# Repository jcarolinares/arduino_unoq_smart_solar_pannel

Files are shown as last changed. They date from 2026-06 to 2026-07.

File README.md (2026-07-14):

# 🌞 UNO Q Smart Solar Pannel

A small solar pannel system that orient solar pannels automatically to get as much energy as possible, protects them from overheat and extreme weather conditions, and autoclean them using the Arduino UNO Q advanced Edge AI Features.

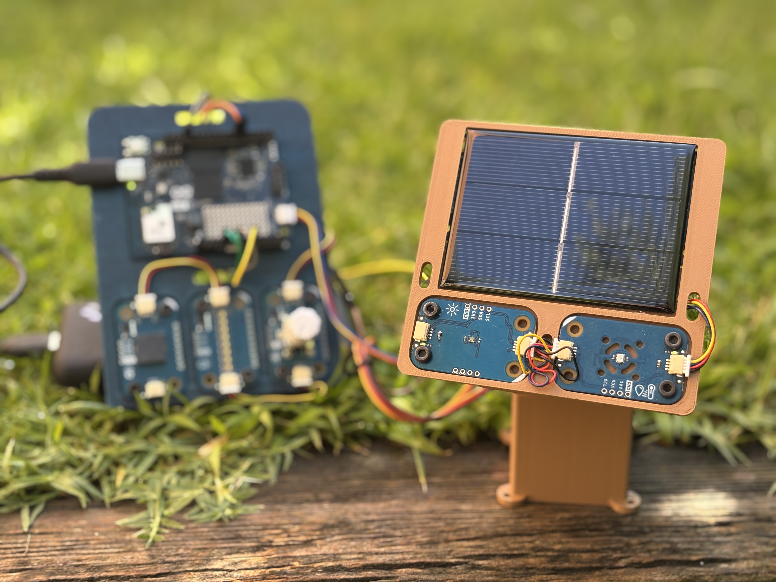
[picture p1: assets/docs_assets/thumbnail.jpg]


Youtube video below:

<a href="http://www.youtube.com/watch?feature=player_embedded&v=w9L78aqJsKc
  " target="_blank">Arduino UNO Q Solar Panel</a>

The UNO Q Smart Solar Panel system it is a little project intended to be used to learn about Edge AI applied to Green Energy Systems like Solar Panel systems. It is fully open sourced and you can 3D printed, mount and program it on your own!

[Youtube Video Link](https://youtu.be/w9L78aqJsKc)

## Features

* Fully accesible and Open Source, 3D print the pieces and use the cheap solar panel, servomotors and Modulinos to make it work.
* The system scan the sky and save the information into a database auto orienting the sonal panel to the best position to get more energy at any time.
* The Linux system take cares of Edge AI features, like general forecast, interactive local dashboard and much more, while the microcontroller gets information from the sensors and move the servomotors.
* If the weather forecast is snowy, or there is a sand's storm incoming, the Linux system informs the microcontroller to put the solan panel in emergency mode, keeping the solar panel as vertical as possible to protect it from the sand, snow, etc.
* If it is night or foggy, being too dark to get energy from the sand, the solar panel will read the low values of voltage and put it in home position (panel in horizontal) waiting for the right conditions to get energy again.
* The system is able to get not only read the values from the actual energy of the solar panel, but also get the infrared values of the sun thanks to the Modulino light. Which makes the system more efficient and able to detect where is position to get more energy from the sun.
* Thanks to the Modulino Thermo, system is able to know the temperature and humidity of the solar panel in real time. Protecting the solar panel when temperatures reachs danger limits for the panel like more than 60 celsius degrees.
* The solar panel is able to detect anomaly vibrations thanks to the Modulino IMU, stopping the whole system in case a serious problem is detected.
* The system is able to autoclean itself from dust, snow and sand, thanks to the Modulino Vibro, that makes, like Nasa's martian rovers do, to vibrate the whole solar panel to clean it.

### The real-time dashboard

The project shows on your network a small webpage dashboard with all the information in real time about what is happening.

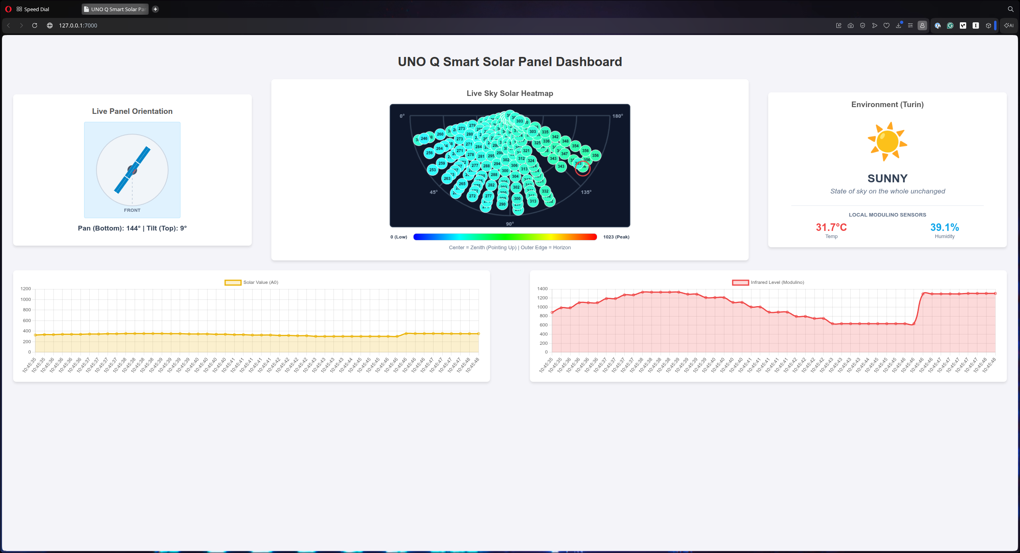
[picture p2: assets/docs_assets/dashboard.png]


* The Solar Panel orientation in real-time.
* The Live Sky HeatMap about the solar voltage readings from the solar panel to understand the best position for getting energy and the current position of the solar panel.
* The actual weather forecast of the place where the solar panel is installed and the real-time temperature and humidity of the solar panel itself.
* A real-time graph about the energy taking by the solar panel overtime.
* A real-time graph about the infrared light that the solar panel is getting overtime.

## Hardware Required

- 1x Arduino UNO Q
- 1x Small Solar Panel of 80 cm x 60 cm with a maximum voltage of 3 VDC.
- 2x Servomotors MG90 to move the solar panel.
- 1x Modulino Movement to detect sanomalies in the movement or even raining drops!
- 1x Modulino Light to read natural and infrared light
- 1x Modulino Vibro to autoclean the solar panel making it to vibrate.
- 1x Modulino Thermo to get the temperature and humidity of the solar panel

## Software Required

- Arduino App Lab
- Internet connection

## 3D Printed Parts

You can find the 3D parts to print and Freecad source file at the folder "3D Models" inside this repository.

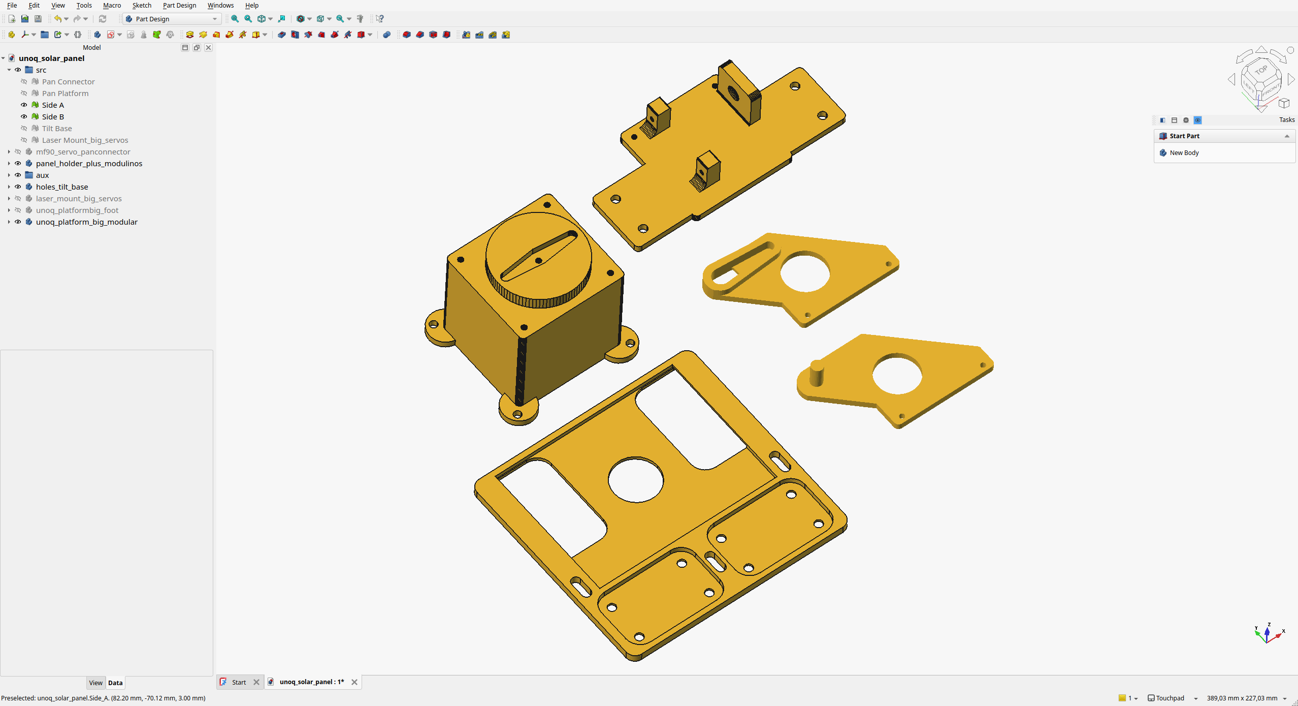
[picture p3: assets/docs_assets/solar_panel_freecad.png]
Freecad Solar Panel Parts


### 3D Printing

No special instructions are required to print your solar panel. Standard PLA is a good material to use but if you are going to put your solar panel long hours exposed to the sun can be melted easily, consider to print the parts in PETG if that is the case.
No supports are required. Use standard 15%/20% Infill and a nice 0.2 layer height.

### Assembly

Assembly is extremely easy, just follow the original instructions [here](https://www.hackster.io/TheSmallWonder/pan-tilt-assembly-for-mg90s-servos-da32c).

### Credits about the 3D parts

The design was created using as a base the project made by "The Small Wonder"

[Pan & Tilt Assembly for MG90S Servos](https://www.hackster.io/TheSmallWonder/pan-tilt-assembly-for-mg90s-servos-da32c6)

This design was used as base and some pieces were reused while another new parts were totally created from scrach, some of them were customized too. Use the Freecad file to make your own modifications if need, like adapting the solar panel holder piece for any other kind of solar panel!

## License

This project was created by Julián Caro Linares for Arduino INC under an Open Source Creative Common Share Alike license, CC-BY-SA

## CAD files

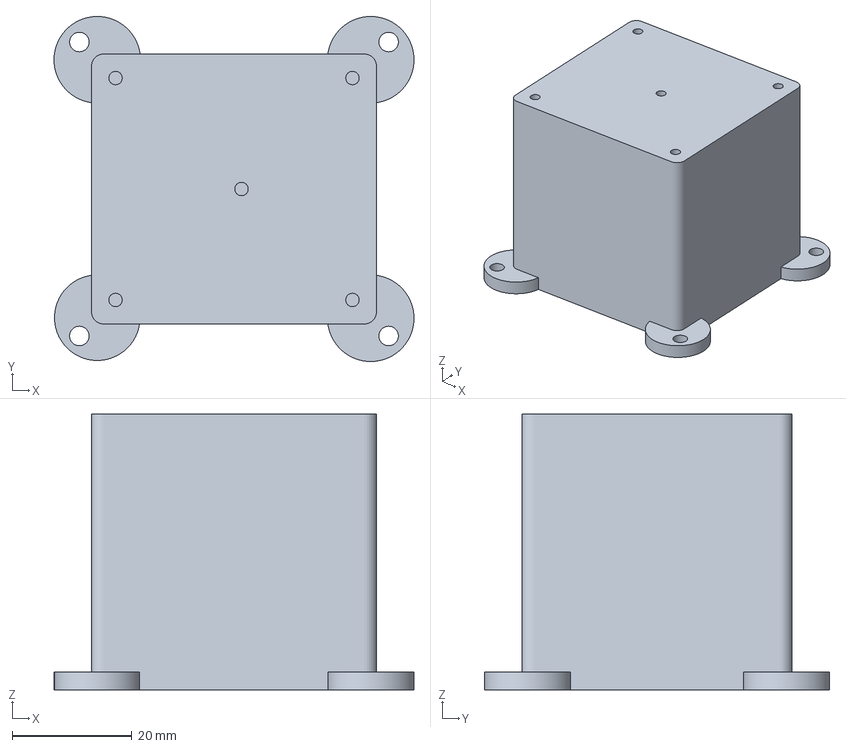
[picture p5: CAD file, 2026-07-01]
3D Models/v0_unoq_solar_panel-unoq_platform_big_modular.3mf
60.0 x 57.5 x 46.0 mm

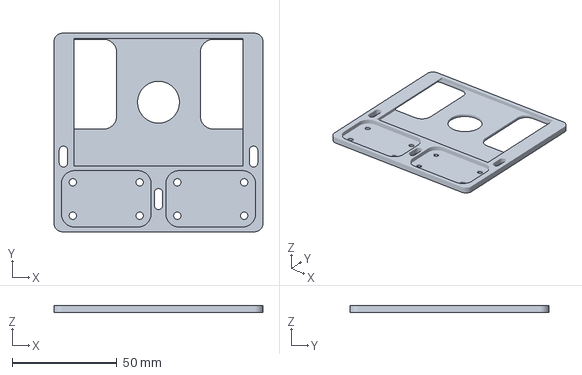
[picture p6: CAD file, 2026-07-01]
3D Models/v1_unoq_solar_panel-panel_holder_plus_modulinos.3mf
100.0 x 95.0 x 3.50 mm

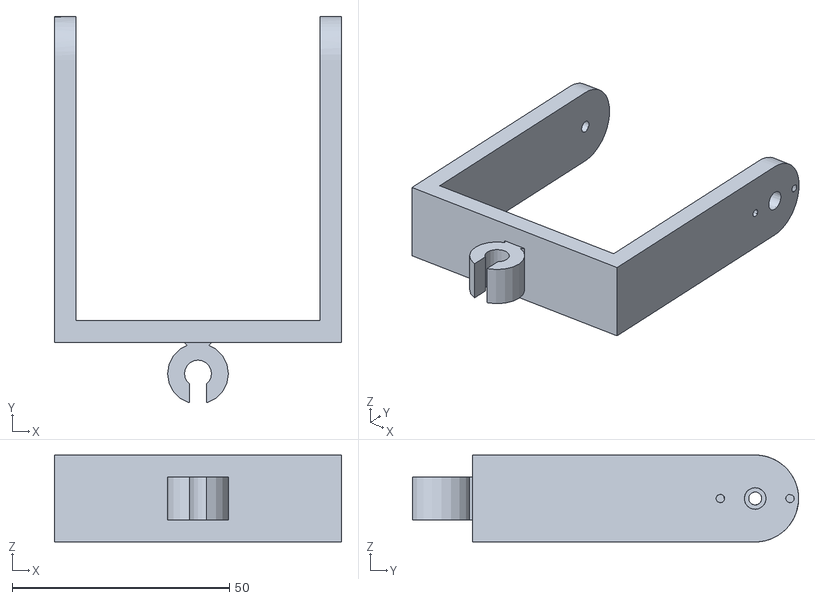
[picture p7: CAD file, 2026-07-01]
3D Models/Laser Mount_big_servos.stl
66.0 x 88.8 x 20.0

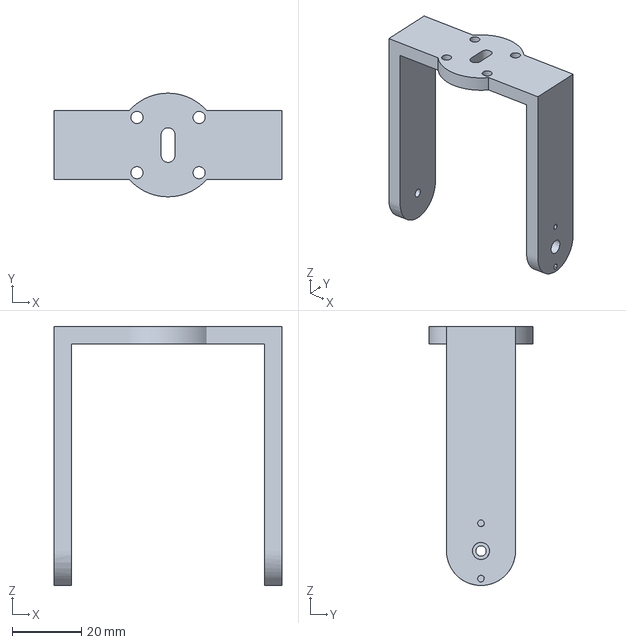
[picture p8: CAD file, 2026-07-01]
3D Models/v0_unoq_solar_panel-laser_mount_big_servos.3mf
66.0 x 30.0 x 75.0 mm

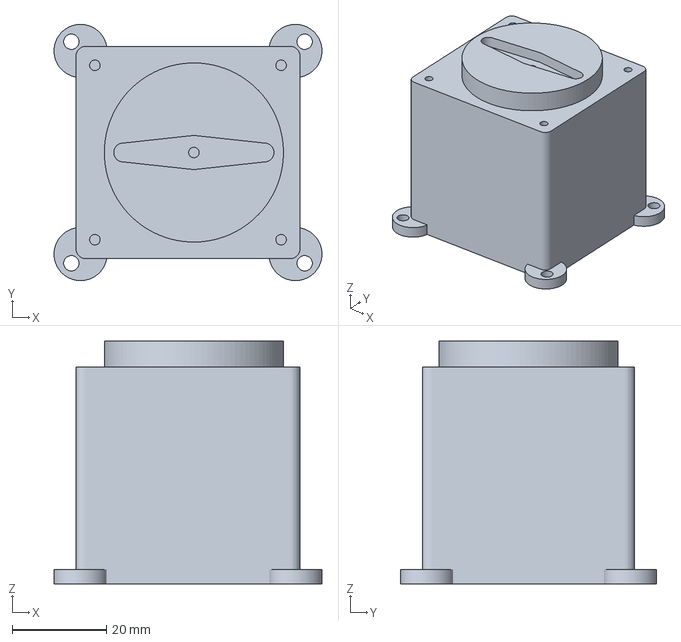
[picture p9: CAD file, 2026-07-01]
3D Models/v0_unoq_solar_panel-unoq_platformbig_foot.3mf
56.9 x 54.4 x 51.5 mm

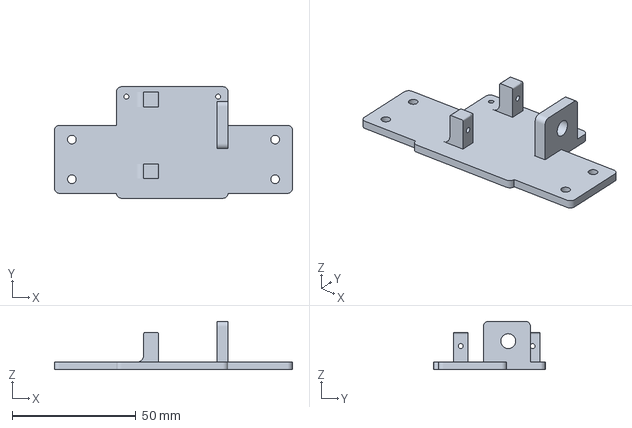
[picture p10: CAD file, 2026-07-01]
3D Models/V0_unoq_solar_panel-holes_tilt_base.3mf
96.0 x 45.0 x 19.5 mm

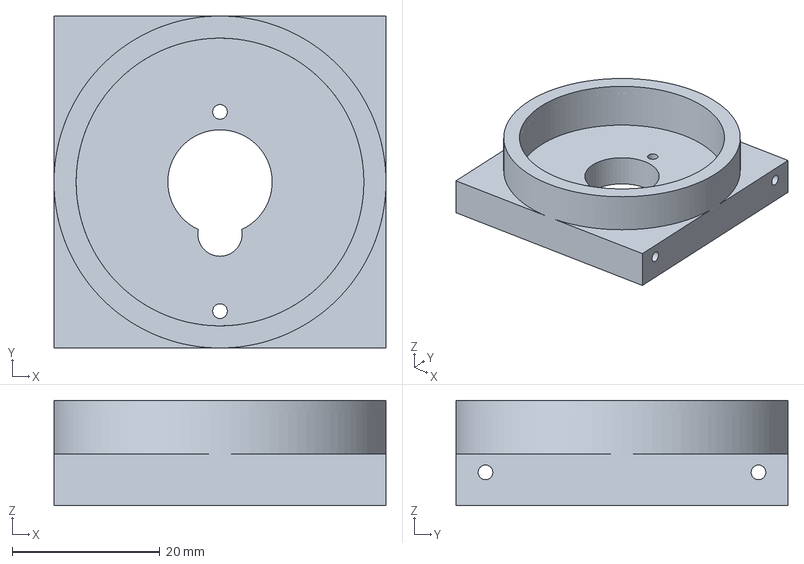
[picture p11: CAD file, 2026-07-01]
3D Models/v0_unoq_solar_panel-mf90_servo_panconnector.3mf
45.0 x 45.0 x 14.2 mm

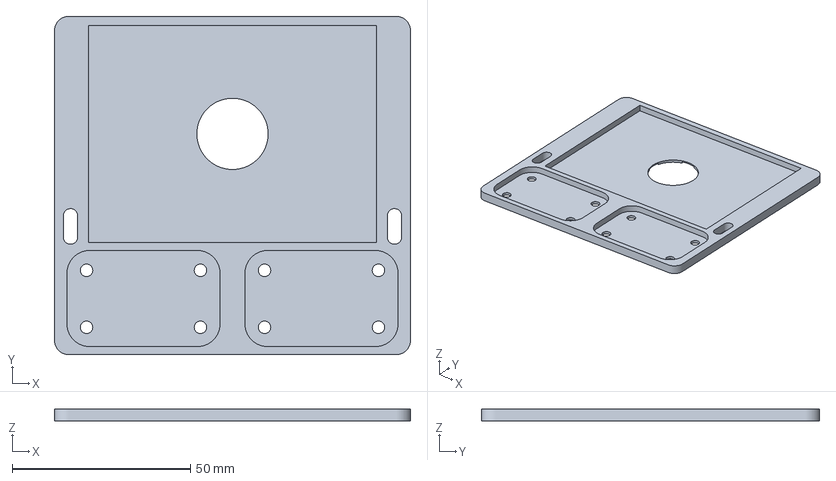
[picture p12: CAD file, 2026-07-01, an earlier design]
3D Models/v0_unoq_solar_panel-panel_holder_plus_modulinos.3mf
100.0 x 95.0 x 3.50 mm

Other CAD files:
3D Models/unoq_solar_panel.FCStd

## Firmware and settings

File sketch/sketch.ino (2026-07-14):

/*
  UNO Q Smart Solar Pannel System
  Created by Julián Caro Linares for Arduino INC
  CC-BY-SA
*/

#include <Arduino_RouterBridge.h>
#include <Arduino_Modulino.h>
#include "Servo.h"

// Servo Objects
Servo servo_bottom;
Servo servo_top;

// Modulino Objects
ModulinoLight light;
ModulinoThermo thermo;
ModulinoMovement movement;
ModulinoVibro vibro;

// Servo Pins
const int servoPin_bottom = 5;
const int servoPin_top = 6;

// Solar Panel Voltage analog Pin
const int solarPin = A0;

// Servo saved positions & Scanning Variables
const int idle_position = 90;

// Independent Bottom (Pan) Limits
const int bottom_min_position = 15;
const int bottom_max_position = 155;

// Independent Top (Tilt) Limits
const int top_min_position = 5; 
const int top_max_position = 90; 

const int scan_step_degrees = 10; 
const int scan_delay_ms = 300; // Delay AFTER reaching the position to let sensors settle

// Calculate the required matrix sizes for the auto scanning
const int num_bottom_steps = ((bottom_max_position - bottom_min_position) / scan_step_degrees) + 1;
const int num_top_steps = ((top_max_position - top_min_position) / scan_step_degrees) + 1;

// 2D Arrays to store the sensor values
int scan_matrix[num_bottom_steps][num_top_steps];
int ir_matrix[num_bottom_steps][num_top_steps];

// Global Memory for the last known best position
int last_best_bottom = idle_position;
int last_best_top = idle_position;

// --- GLOBAL VARIABLES FOR PYTHON BRIDGE ---
int latest_solar_val = 0;
int latest_ir_val = 0;

// Non-blocking Timer Variables
unsigned long previousScanTime = 0;
const unsigned long scanInterval = 10000  // Time in minutes between auto scanners. 10 minutes by default. 

// Modulino Variables
int lux = 0;           
int luxCalibrated = 0; 
int ir = 0;            
float celsius = 0;
float humidity = 0;
float x_accel, y_accel, z_accel;
float roll, pitch, yaw;

// Alerts
bool weather_alert = false;

// ==========================================
// FORWARD DECLARATIONS
// ==========================================
void set_weather_alert(bool state);
void scanForMaxValue(int stepSize, int stepDelay);
void printScanMatrix();
void printIRMatrix();
void panel_cleaning();
void smoothMove(int target_b, int target_t);
int get_solar();
int get_infrared();
int get_bottom();
int get_top();


void setup() {
  Serial.begin(9600);
  Bridge.begin();

  // Bridge providers to communicate with the Python part
  Bridge.provide("set_weather_alert", set_weather_alert);
  Bridge.provide("get_solar", get_solar);
  Bridge.provide("get_infrared", get_infrared);
  Bridge.provide("get_bottom", get_bottom);
  Bridge.provide("get_top", get_top);
  Bridge.provide("get_temp", get_temp);
  Bridge.provide("get_humidity", get_humidity);

  // GPIO Setup
  pinMode(LED_BUILTIN, OUTPUT);
  pinMode(solarPin, INPUT); 

  // Modulino init
  Modulino.begin();
  light.begin();
  thermo.begin();
  vibro.begin();

  // Servomotors init
  servo_bottom.attach(servoPin_bottom);
  servo_top.attach(servoPin_top);
  
  // Set initial servo home position
  servo_bottom.write(idle_position);
  servo_top.write(idle_position);
  delay(20000); // We wait around 20 seconds to wait to the Python part to build and launch the Dashboard Interface
}


void loop() {
  int solarValue = analogRead(solarPin);

  // Sensors Updates
  light.update();
  movement.update();

  // Sensors adquisition
  lux = light.getAL();              
  luxCalibrated = light.getLux();   
  ir = light.getIR();               
  
  latest_solar_val = solarValue;
  latest_ir_val = ir;
  
  celsius = thermo.getTemperature();
  humidity = thermo.getHumidity();

  // Main Control Loop State Machine
  if (weather_alert == true){ // Weather Alert Emergency Mode
    smoothMove(bottom_min_position, top_min_position);
    panel_cleaning();
  } 
  else if (solarValue < 100) { // Night and Too low light Mode
    smoothMove(idle_position, idle_position);
  }
  else if (celsius > 60) { // Excesive Heat Alert Emergency Mode
    Serial.println("Excessive heat alert. Safe mode activated");
    smoothMove(idle_position, top_min_position);
  }
  else { // Normal mode with auto scanning mode
    unsigned long currentMillis = millis();
    if (currentMillis - previousScanTime >= scanInterval || previousScanTime == 0) {
      Serial.println("Starting Sky Scan...");
      scanForMaxValue(scan_step_degrees, scan_delay_ms);
      previousScanTime = millis(); 
    }
  }
  
  delay(1000); // System's Update Interval
}




// -------------------------------------------------------------------------------
// Function: smoothMove
// Purpose: Moves servos degree-by-degree to have a smooth and constant movement
// -------------------------------------------------------------------------------
void smoothMove(int target_b, int target_t) {
  int current_b = servo_bottom.read();
  int current_t = servo_top.read();

  // Keep looping until BOTH servos have reached their targets
  while (current_b != target_b || current_t != target_t) {
    
    // Step the bottom servo
    if (current_b < target_b) current_b++;
    else if (current_b > target_b) current_b--;

    // Step the top servo
    if (current_t < target_t) current_t++;
    else if (current_t > target_t) current_t--;

    // Write the new incremental positions
    servo_bottom.write(current_b);
    servo_top.write(current_t);
    
    // A 15ms delay is the industry standard for smooth servo sweeps
    delay(15); 
  }
}

// ---------------------------------------------------------------------------------------------------------------
// Function: scanForMaxValue
// Purpose: Move the solar panel to each position, gets information from the sensors and show it and store it
// ---------------------------------------------------------------------------------------------------------------
void scanForMaxValue(int stepSize, int stepDelay) {
  int maxValueFound = -1;
  int bestBottomPos = idle_position;
  int bestTopPos = idle_position;
  
  bool goingUp = true; 

  for (int b = bottom_min_position; b <= bottom_max_position; b += stepSize) {
    // Smooth move to the new bottom column (keeping top where it is)
    smoothMove(b, servo_top.read());
    
    int b_idx = (b - bottom_min_position) / stepSize;
    
    if (goingUp) {
      for (int t = top_min_position; t <= top_max_position; t += stepSize) {
        
        // Smooth move to the next scan point
        smoothMove(b, t);
        delay(stepDelay); // Let the panel stop shaking before reading sensors
        
        int currentSolarValue = analogRead(solarPin);
        light.update();
        int currentIRValue = light.getIR();
        
        latest_solar_val = currentSolarValue;
        latest_ir_val = currentIRValue;
        
        int t_idx = (t - top_min_position) / stepSize;
        scan_matrix[b_idx][t_idx] = currentSolarValue;
        ir_matrix[b_idx][t_idx] = currentIRValue;
        
        if (currentSolarValue > maxValueFound) {
          maxValueFound = currentSolarValue;
          bestBottomPos = b;
          bestTopPos = t;
        }
      }
    } else {
      for (int t = top_max_position; t >= top_min_position; t -= stepSize) {
        
        // Smooth move to the next scan point
        smoothMove(b, t);
        delay(stepDelay);
        
        int currentSolarValue = analogRead(solarPin);
        light.update();
        int currentIRValue = light.getIR();
        
        latest_solar_val = currentSolarValue;
        latest_ir_val = currentIRValue;
        
        int t_idx = (t - top_min_position) / stepSize;
        scan_matrix[b_idx][t_idx] = currentSolarValue;
        ir_matrix[b_idx][t_idx] = currentIRValue;
        
        if (currentSolarValue > maxValueFound) {
          maxValueFound = currentSolarValue;
          bestBottomPos = b;
          bestTopPos = t;
        }
      }
    }
    
    goingUp = !goingUp; 
  }

  last_best_bottom = bestBottomPos;
  last_best_top = bestTopPos;

  // After the scanning, it moves to the best position to capture light energy
  smoothMove(bestBottomPos, bestTopPos);

  printScanMatrix();
  printIRMatrix();

  Serial.println("=================================");
  Serial.println("TARGET ACQUIRED (Source: Solar Panel A0)");
  Serial.print("Peak Value: ");
  Serial.print(maxValueFound);
  Serial.print(" at (Bottom: ");
  Serial.print(bestBottomPos);
  Serial.print("°, Top: ");
  Serial.print(bestTopPos);
  Serial.println("°)");
  Serial.println("=================================");
}

// ---------------------------------------------------------
// Print Functions & Utilities
// ---------------------------------------------------------
void printScanMatrix() {
  Serial.println("\n--- Sky Heatmap [Data Source: SOLAR PANEL (A0)] ---");
  Serial.print("B\\T\t");
  for (int t = top_min_position; t <= top_max_position; t += scan_step_degrees) {
    Serial.print(t);
    Serial.print("\t");
  }
  Serial.println();
  for (int b_idx = 0; b_idx < num_bottom_steps; b_idx++) {
    int b_angle = bottom_min_position + (b_idx * scan_step_degrees);
    Serial.print(b_angle);
    Serial.print("\t");
    for (int t_idx = 0; t_idx < num_top_steps; t_idx++) {
      Serial.print(scan_matrix[b_idx][t_idx]);
      Serial.print("\t");
    }
    Serial.println();
  }
  Serial.println("-----------------------");
}

void printIRMatrix() {
  Serial.println("\n--- Sky Heatmap [Data Source: MODULINO INFRARED (IR)] ---");
  Serial.print("B\\T\t");
  for (int t = top_min_position; t <= top_max_position; t += scan_step_degrees) {
    Serial.print(t);
    Serial.print("\t");
  }
  Serial.println();
  for (int b_idx = 0; b_idx < num_bottom_steps; b_idx++) {
    int b_angle = bottom_min_position + (b_idx * scan_step_degrees);
    Serial.print(b_angle);
    Serial.print("\t");
    for (int t_idx = 0; t_idx < num_top_steps; t_idx++) {
      Serial.print(ir_matrix[b_idx][t_idx]);
      Serial.print("\t");
    }
    Serial.println();
  }
  Serial.println("-----------------------");
}

// -------------------------------------------------------------------------------------------
// Function: panel_cleaning
// Purpose: Makes the Modulino Vibro Motor to shake the solar panel from snow, dust or sand
// -------------------------------------------------------------------------------------------
void panel_cleaning() {
  smoothMove(idle_position, idle_position);
  delay(100);
  vibro.on(5000);
  delay(1000);
  vibro.off();
  delay(10000);
}

// -----------------------------------------------------------------------------------------------
// Function: set_weather_alert
// Purpose: Moves the Solar Panel to a save position to avoid damage, as much vertical as possible
// -----------------------------------------------------------------------------------------------
void set_weather_alert(bool state) {
  if (state == true){
    digitalWrite(LED_BUILTIN, LOW);
    Serial.println("Weather Alert Detected");    
    weather_alert = true;
  }
  else{
    digitalWrite(LED_BUILTIN, HIGH);
    Serial.println("Weather Alert Finished");    
    weather_alert = false;
  }
}

// ==========================================
// PYTHON BRIDGE GETTER FUNCTIONS
// ==========================================
int get_solar() { return latest_solar_val; }
int get_infrared() { return latest_ir_val; }
int get_bottom() { return servo_bottom.read(); }
int get_top() { return servo_top.read(); }
float get_temp() { return celsius; }
float get_humidity() { return humidity; }

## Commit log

2026-06-21 Servomotors minimum and maximums separated. New default numbers
2026-07-01 3D Model Added
    3D Model Added
    [Laser Mount_big_servos.stl, V0_unoq_solar_panel-holes_tilt_base.3mf, unoq_solar_panel.FCStd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]
